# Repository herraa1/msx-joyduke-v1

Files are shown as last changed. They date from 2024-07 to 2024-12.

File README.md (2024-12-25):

# Microsoft Xbox Original controller adapter for MSX (msx-joyduke) v1

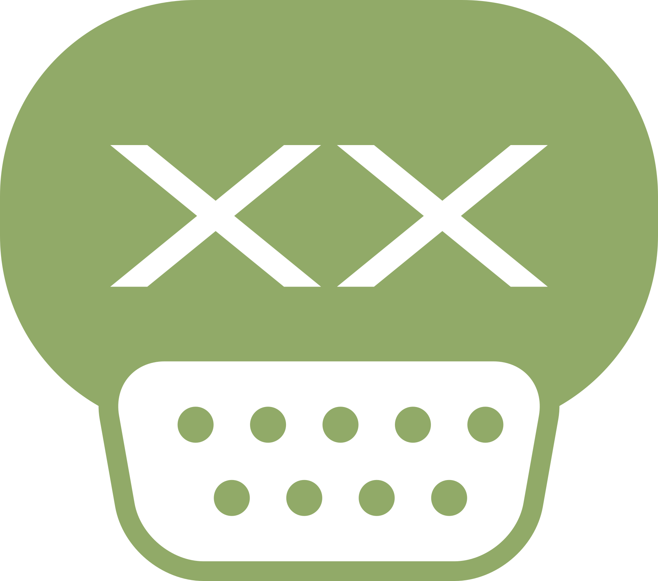
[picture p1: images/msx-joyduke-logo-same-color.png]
[](images/msx-joyduke-logo-same-color.png)

Connect [Microsoft Xbox Original controllers](https://en.wikipedia.org/wiki/Xbox_controller) to [MSX computers](https://www.msx.org/wiki/).

> [!NOTE]
>
> No build instructions are yet provided, but if you are brave enough go for the [recommended build](#recommended-build).
>

## Introduction

The msx-joyduke v1 is an adapter that allows connecting Microsoft Xbox Original controllers to [MSX general purpose I/O ports](https://www.msx.org/wiki/General_Purpose_port).

The main features of the msx-joyduke v1 adapter are:
* made of widely available electronic components
* behaves as a cord extension between the MSX computer and the Microsoft Xbox Original controller
* uses a female standard DE9 connector on the adapter's MSX joystick side
* uses a Xbox Controller socket on the adapter's Microsoft Xbox Original controller side
* formally requires an external USB power supply as the adapter draws slightly more current than a MSX general purpose I/O interface can officially provide
* optionally, can be powered using a MSX general purpose I/O interface without an external power supply if your MSX can safely supply enough current
* power consumption of ~20mA for the adapter itself, between ~55mA and ~85mA depending on the Xbox controller connected
* serial debug provides information about the operation of the adapter

## [Hardware](hardware/kicad/)

The msx-joyduke v1 adapter uses an [Atmega328p](https://en.wikipedia.org/wiki/ATmega328) and a [MAX3421](https://www.analog.com/media/en/technical-documentation/data-sheets/max3421e.pdf) to convert the [Microsoft Xbox Original controller USB signalling](https://xboxdevwiki.net/Xbox_Input_Devices#USB_Adapters) to the [MSX joystick standard signalling](https://www.msx.org/wiki/Joystick_control).

A two-sided printed circuit board (PCB) is used to put together all components:
* An Atmega328p as the main MCU working at +3.3V and clocked at 8MHz
* A MAX3421 USB Host Controller with SPI interface
* A TPS2051C 500mA current limited switch for the host controller USB port
* An AMS1117-3.3 regulator to convert the 5V from the joystick or the mini USB port to the 3.3V used by the Atmega328p and the MAX3421 chips
* Two 74LS03 quad 2-input NAND gates with open collectors to completely mimic the standard MSX joystick behavior
* A PTC fuse to minimize damage to the MSX computer in case something goes wrong with the board
* Several additional required components (crystals/resonators, diodes, leds, resistors, ceramic capacitors and alumionium capacitors)
* A 9pin PH2.0 connector is used to connect the MSX cable extension
* A 5pin PH2.0 connector is used to connect the Xbox cable extension
* A 2.54 pitch debug header is added for serial debug and programming
* An ICSP header is provided for burning a bootloader or to flash the chip using a hardware programmer

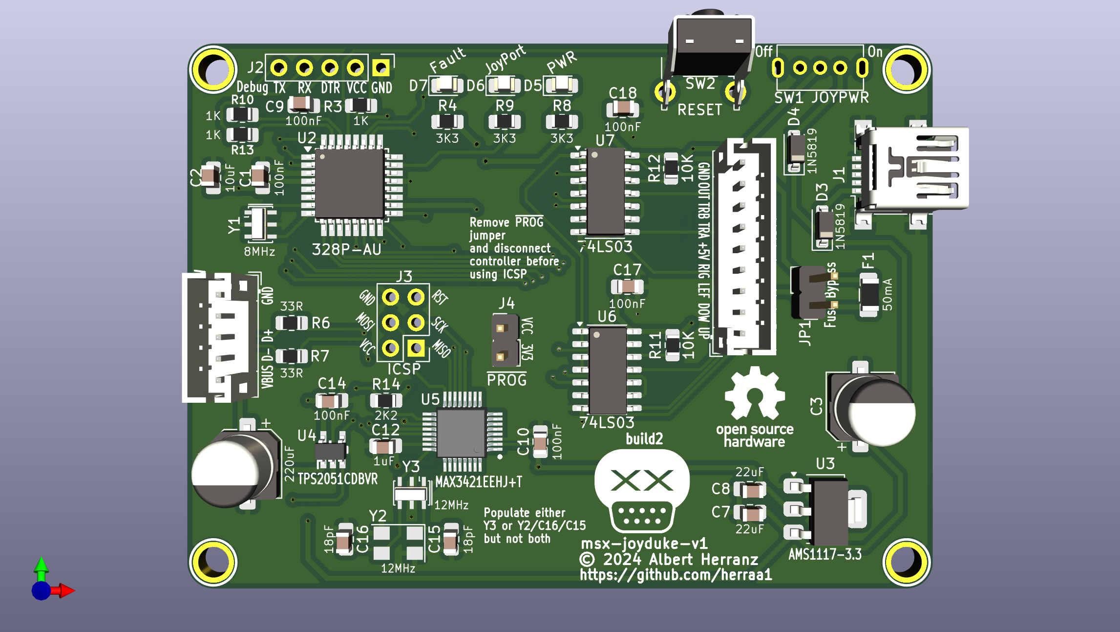
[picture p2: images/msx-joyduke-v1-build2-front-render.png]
[](images/msx-joyduke-v1-build2-front-render.png)
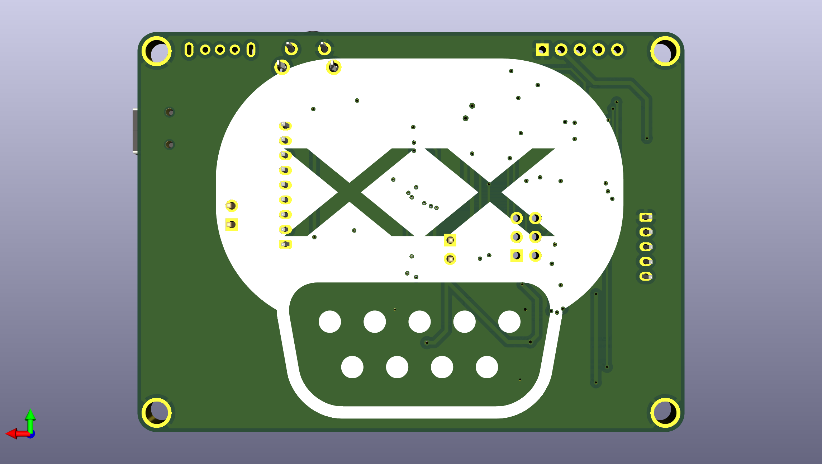
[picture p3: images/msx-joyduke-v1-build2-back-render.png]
[](images/msx-joyduke-v1-build2-back-render.png)

Connection to the MSX general purpose I/O port is implemented using a DE9 joystick extension cable with a female DE9 connector on one side and a loose end on the other side.
The MSX joystick extension cable loose end is wired according to the following pinout mapping.

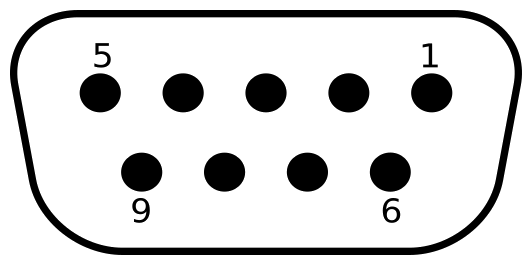
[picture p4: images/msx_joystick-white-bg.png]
| [](images/msx_joystick-white-bg.png) |
|:--|
| MSX joystick connector pinout, from controller plug side |

| MSX side pin | Cable color (may vary) | Signal |
| --- | --- | --- |
| 5 | Brown | +5v |
| 4 | Orange | RIGHT  |
| 3 | Grey | LEFT |
| 2 | Black | DOWN |
| 1 | Red | UP |
| 6 | Green | TRIGA  |
| 7 | White | TRIGB  |
| 8 | Blue | OUT |
| 9 | Yellow | GND |

The msx-joyduke-v1 is fully compatible with MSX joysticks and honors the pin8 (OUT) signal.

Connection to the Microsoft Xbox Original controller is done via a PC USB for Microsoft Xbox Original controller converter adapter cable with a male socket (the ones present on the Xbox console itself).

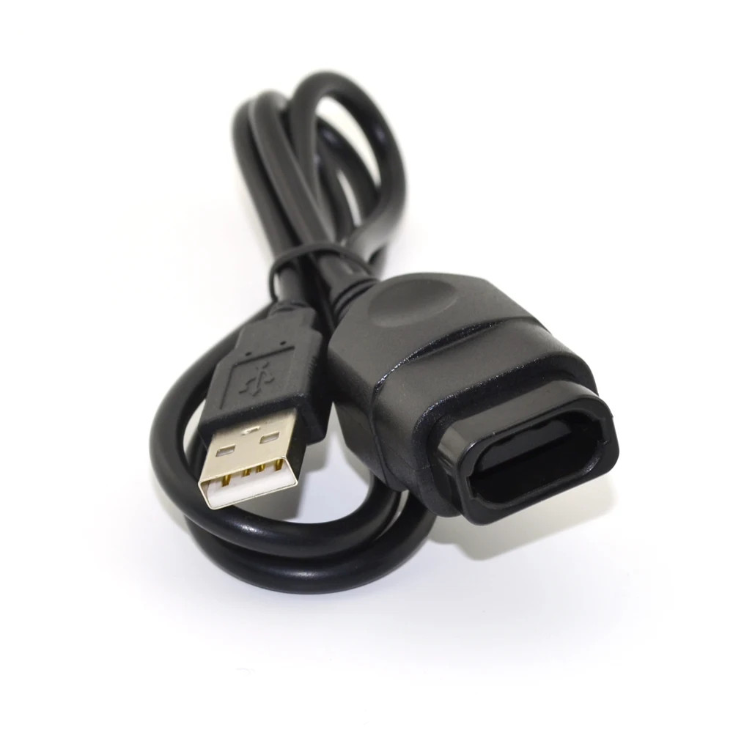
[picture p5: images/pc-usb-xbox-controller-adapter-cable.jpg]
| [](images/pc-usb-xbox-controller-adapter-cable.jpg) |
|:--|
| PC USB for Microsoft Xbox Original controller adapter cable |

The cable is severed to get rid of the USB side (which can be used for other projects) exposing the USB wiring.

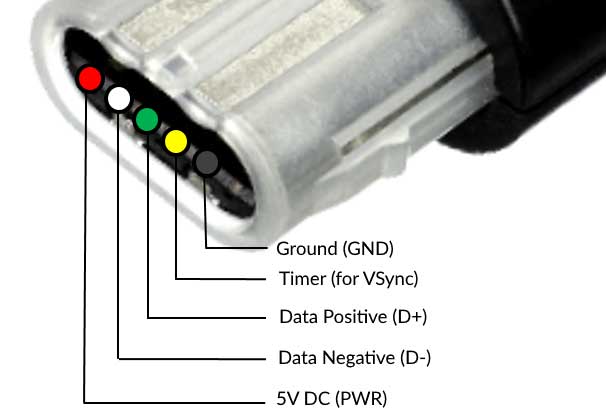
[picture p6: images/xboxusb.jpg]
| [](images/xboxusb.jpg) |
|:--|
| Microsoft Xbox Original connector pinout, from Microsoft Xbox Original controller side |

| Cable color official | Signal | Comment |
| ---| --- | --- |
| Green | D+ | USB Data + |
| White | D- | USB Data - |
| Yellow | VSync | (not used) |
| Black | GND | ground |
| Red | +5V | +5V power |

The Microsoft Xbox Original controller uses 5V for power and logic.

### Recommended Build

Please, use [msx-joyduke-v1 Build2](#build2) for making new boards.

### [Build2](hardware/kicad/msx-joyduke-v1-build2)

[Bill Of Materials (BoM)](https://html-preview.github.io/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)

This is the first publicly released build of the msx-joyduke adapter.

## [Firmware](firmware/msx-joyduke-v1/)

The msx-joyduke v1 adapter firmware uses the [USB Host Shield 2.0 library](https://github.com/felis/USB_Host_Shield_2.0) to read the Microsoft Xbox Original controller status.

While developing the firmware, I noticed that some Xbox Original controllers were not working as expected. After a bit of troubleshooting the root cause was found and a [modification](https://github.com/felis/USB_Host_Shield_2.0/commit/b92fa02546dddd2278cd411e5d0e2d2ff614c8d8) to the library has been submitted and merged to fix the problem.

The following elements are used as inputs:
* digital pad (D-Pad), as direction arrows
* left and right analog pad as direction arrows
* A button, as Trigger 1
* B button, as Trigger 2

Those elements' status are processed by the msx-joyduke firmware and transformed into MSX general purpose I/O port's signals on the fly.

## [Enclosure](enclosure/)

### Acrylic

A simple acrylic enclosure design for the project is provided to protect the electronic components and provide strain relief for the extension cords.

The enclosure uses a 3mm acrylic sheet.

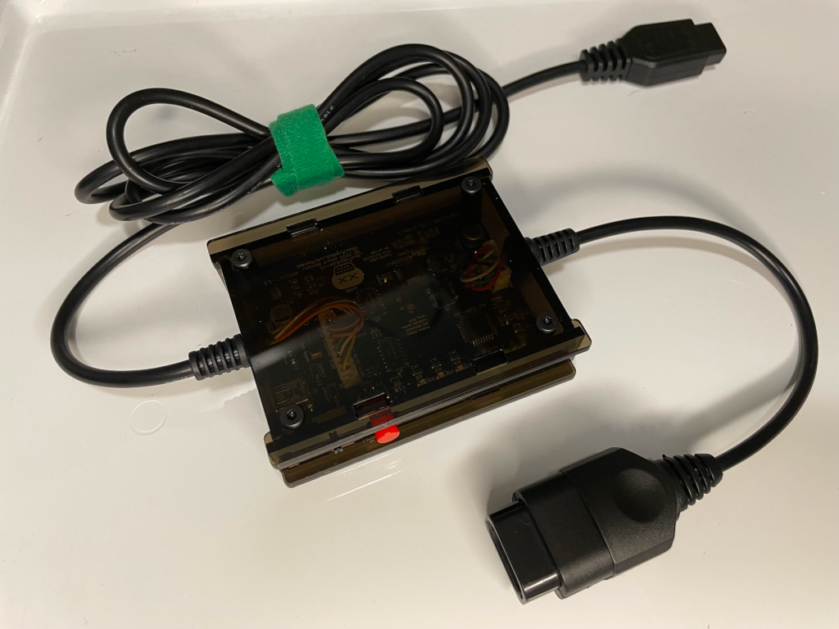
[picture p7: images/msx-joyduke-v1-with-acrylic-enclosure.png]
[](images/msx-joyduke-v1-with-acrylic-enclosure.png)

## Powering the msx-joyduke adapter

The msx-joyduke adapter uses under ~20mA when operating without a controller connected, but the power consumption can rise to ~85mA when an Xbox controller is connected.

On the other hand, a single MSX general purpose I/O interface is capable of delivering up to 50mA according to the MSX standard [^1].

That means that we are slightly over the max current specification for the MSX general purpose I/O interface.

Thus, the safest way to power the msx-joyduke adapter is by powering it via the USB mini connector of the board using an external 5V USB power supply. The board automatically powers up when using the USB mini connector without enabling any switch.

Nevertheless, even if the MSX especification puts such a low limit on the current that can be drawn from a general purpose I/O interface, real MSX hardware usually can safely deliver enough current for the msx-joyduke adapter to work correctly without harming our beloved classic computers.

Taking that into account, the msx-joyduke adapter has been enabled to be optionally powered by the a MSX general purpose I/O interface port.

To enable powering the msx-joyduke adapter from the _MSX Joystick Port_, the switch SW1 _JOYPWR_ must be first turned on by sliding the switch handle to the left.

> [!NOTE]
> A [1N5819 SMD Schottky diode](https://www.diodes.com/assets/Datasheets/1N5819HW.pdf) D4 is used to avoid leaking current from the msx-joyduke adapter to the MSX in case the msx-joyduke adapter is powered by USB while the _JOYPWR_ switch is ON.
> Another [1N5819 SMD Schottky diode](https://www.diodes.com/assets/Datasheets/1N5819HW.pdf) D3 prevents backpowering the USB side from the MSX side.
> And a Positive Temperature Coeficient (PTC) resettable fuse F1 of 50mA protects the MSX general purpose I/O interface port from excess of current in case something goes horribly wrong on the msx-joyduke adapter side.

To power the msx-joyduke adapter using a MSX general purpose I/O interface we must first understand how the PTC protections on the msx-joyduke adapter are implemented.

The selected PTC is rated for 50mA which is the so called Hold Current (the maximum current that can flow in normal operation). There is also the Trip Current (the minimum current necessary for the PTC to move to high-resistance state) which for the selected PTCs is around 100mA. Those thresholds are dependent on temperature and voltage. And to make things more undeterministic, the behavior of the PTC when current is between those thresholds is undefined (it may trip or not).

In normal operation and for a room temperature of around 25 degrees Celsius, the selected PTCs in practice never trip below 75mA.

> [!NOTE]
> Depending on the exact PTCs installed, the trip current may be slightly different and the adapter may trip at a different point. Unless you buy the PTCs from a reliable source, it is very difficult to know the exact PTC specifications. 
>
> Remember that the PTCs are provided as a safeguard in case something goes really wrong on the adapter, not to act as an exact current limiter to strictly comply with the 50mA per-port MSX specification.

A jumper JP1 can be used to bypass the PTC protections for the _MSX Joystick Port_.

> [!WARNING]
> Bypassing the PTC protection may damage your MSX computer.
> Do not bypass the PTC protections unless you known what you are doing.

By closing JP1 and **if our MSX computer can safely provide more than 85mA on a single MSX general purpose I/O interface**, we can connect the _MSX Joystick Port_ to the MSX computer and turn on the SW1 _JOYPWR_ switch to power the msx-joyduke adapter using a single joystick port.

In summary, we can use the following options to power the msx-joyduke adapter (from safest to less safe):
* via the board USB mini conector
  * turn off the SW1 _JOYPWR_ switch
  * connect a 5V USB power supply to the board USB mini connector
* via one of the MSX general purpose I/O interface, if your MSX can safely provide more than 85mA on each MSX general purpose I/O interface
  * close jumper JP1
  * turn on the SW1 _JOYPWR_ switch
  * connect the _MSX Joystick Port_ to a MSX general purpose I/O interface

## Switches and Buttons

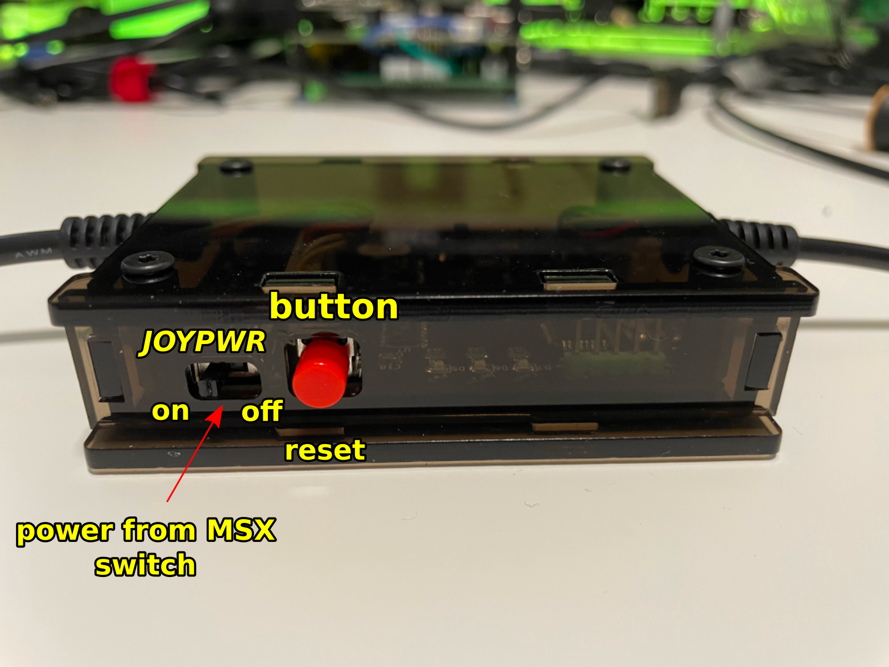
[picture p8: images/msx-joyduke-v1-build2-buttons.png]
[](images/msx-joyduke-v1-build2-buttons.png)

| **Switch** | **State** | **Description** |
|---|---|---|
| _JOYPWR_ | Off | power from MSX computer via a joystick port is off (except logic gates)  |
| _JOYPWR_ | On | board electronics get power from MSX computer via a joystick port |

> [!NOTE]
> If you plug a +5V USB power supply to the USB mini connector, the adapter will turn on unconditionally irrespective of the _JOYPWR_ switch position.
>

| **Button** | **Description** |
|---|---|
| RESET | restart the firmware |

## LED indicators

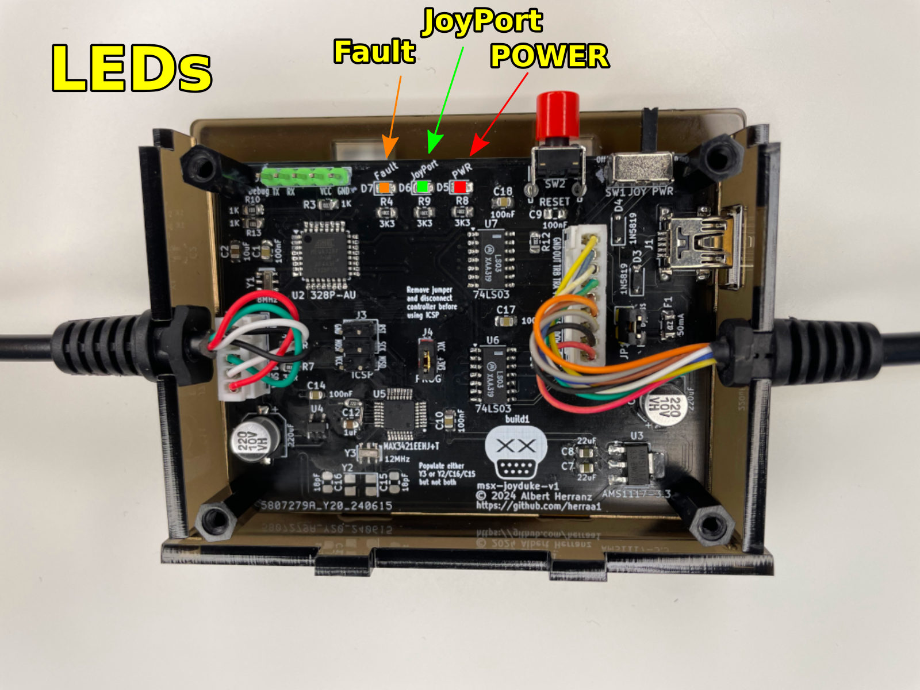
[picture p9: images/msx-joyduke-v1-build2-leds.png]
[](images/msx-joyduke-v1-build2-leds.png)

| **LED** | **State** | **Indication** |
|---|---|---|
| _POWER_ | Off | board is not receiving 3V3 power |
| _POWER_ | Solid Red | board is receiving 3V3 power |
| _JoyPort_ | Off | no Xbox controller connected or recognized |
| _JoyPort_ | Solid Green | Xbox controller connected and ready to use |
| _Fault_ | Off | no power fault detected |
| _Fault_ | Solid Yellow | excess of current detected on the Xbox connector |

## Compatibility Tests

| **Controller** | **Compatible** |
|---|---|
| 045e:0202 Microsoft X-Box pad v1 (US) | YES |
| 045e:0289 Microsoft X-Box pad v2 (US) | YES |

Other Xbox controllers may work but have not been tested.

## References

MSX general purpose I/O port
* https://www.msx.org/wiki/General_Purpose_port

Xbox controller pinout and protocol
* https://chris-donnelly.github.io/xboxpad.html

Atmega328p pinout
- https://camo.githubusercontent.com/18796d8b7673e3b6c14b6bdfb61d86b58c6f0d670398973abd4207afce960277/68747470733a2f2f692e696d6775722e636f6d2f6e6177657145362e6a7067

USB Host Shield 2.0 Library
* https://github.com/felis/USB_Host_Shield_2.0

[^1]: https://www.msx.org/wiki/General_Purpose_port

## Image Sources

* https://www.oshwa.org/open-source-hardware-logo/
* https://en.wikipedia.org/wiki/File:Numbered_DE9_Diagram.svg

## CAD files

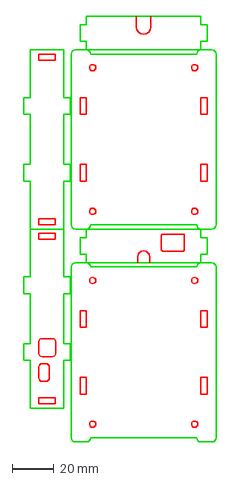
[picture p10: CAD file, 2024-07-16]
enclosure/msx-joyduke-v1-case-acrylic-3mm-ready-to-lasercut.dxf
92.3 x 204.5 mm

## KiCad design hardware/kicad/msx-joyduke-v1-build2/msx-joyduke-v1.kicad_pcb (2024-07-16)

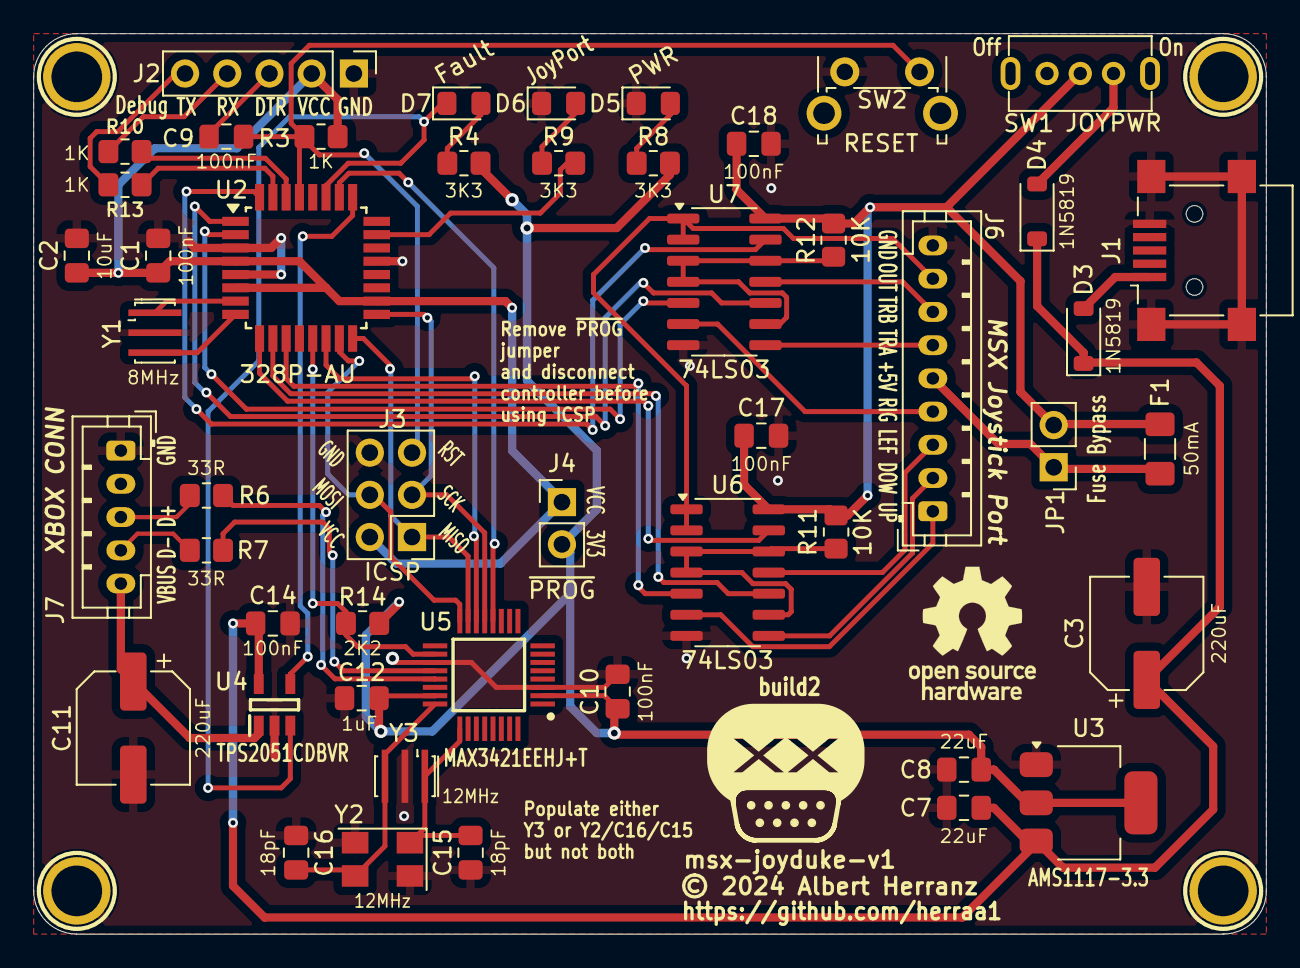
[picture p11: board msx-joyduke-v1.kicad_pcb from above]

Board: 2 copper layers, 74.2 x 54.2 mm, 54 parts (0 on the bottom side), 50 nets.

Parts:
C1, C9, C10, C14, C17, C18: 100nF; C_0805_2012Metric_Pad1.18x1.45mm_HandSolder
C2: 10uF; C_0805_2012Metric_Pad1.18x1.45mm_HandSolder
C3, C11: 220uF; CP_Elec_6.3x5.4
C7, C8: 22uF; C_0805_2012Metric_Pad1.18x1.45mm_HandSolder
C12: 1uF; C_0805_2012Metric_Pad1.18x1.45mm_HandSolder
C15, C16: 18pF; C_0805_2012Metric_Pad1.18x1.45mm_HandSolder
D3, D4: 1N5819; D_SOD-123
D5: PWR; LED_0805_2012Metric_Pad1.15x1.40mm_HandSolder
D6: JoyPort; LED_0805_2012Metric_Pad1.15x1.40mm_HandSolder
D7: Fault; LED_0805_2012Metric_Pad1.15x1.40mm_HandSolder
F1: 50mA; Fuse_1206_3216Metric_Pad1.42x1.75mm_HandSolder
HOLE1, HOLE2, HOLE3, HOLE4: HOLE; Hole_3mm
J1: USB_B_Mini; USB_Mini-B_Lumberg_2486_01_Horizontal
J2: Debug; PinHeader_1x05_P2.54mm_Vertical
J3: ICSP; PinHeader_2x03_P2.54mm_Vertical
J4: ~{PROG}; PinHeader_1x02_P2.54mm_Vertical
J6: MSX Joystick Port; JST_PH_B9B-PH-K_1x09_P2.00mm_Vertical
J7: XBOX CONN; JST_PH_B5B-PH-K_1x05_P2.00mm_Vertical
JP1: Fuse Bypass; PinHeader_1x02_P2.54mm_Vertical
R3, R10, R13: 1K; R_0805_2012Metric_Pad1.20x1.40mm_HandSolder
R4, R8, R9: 3K3; R_0805_2012Metric_Pad1.20x1.40mm_HandSolder
R6, R7: 33R; R_0805_2012Metric_Pad1.20x1.40mm_HandSolder
R11, R12: 10K; R_0805_2012Metric_Pad1.20x1.40mm_HandSolder
R14: 2K2; R_0805_2012Metric_Pad1.20x1.40mm_HandSolder
SW1: JOYPWR; SW_SK-12D07G6-1P2T-6mm
SW2: RESET; SW_Tactile_SPST_Angled_PTS645Vx39-2LFS
SYM1: Logo_Open_Hardware_Large; OSHW-Logo_7.5x8mm_SilkScreen
U2: 328P-AU; TQFP-32_7x7mm_P0.8mm
U3: AMS1117-3.3; SOT-223-3_TabPin2
U4: TPS2051CDBVR; SOT95P280X145-5N
U5: MAX3421EEHJ+T; QFP50P700X700X120-32N
U6, U7: 74LS03; SOIC-14_3.9x8.7mm_P1.27mm
Y1: 8MHz; Resonator_SMD_Murata_CSTxExxV-3Pin_3.0x1.1mm_HandSoldering
Y2: 12MHz; Crystal_SMD_5032-4Pin_5.0x3.2mm
Y3: 12MHz; Resonator_SMD_Murata_CSTxExxV-3Pin_3.0x1.1mm_HandSoldering

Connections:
+3V3_REG: C8.1, C10.1, C12.1, J4.2, R4.2, R8.2, R14.1, U3.2 (VO), U5.2 (VL), U5.23 (VCC)
+5V_FILT: C3.1, C7.1, C14.1, D3.1 (K), D4.1 (K), U3.3 (VI), U4.5 (IN)
/+3V3_LED: D5.2 (A), R8.1
/D0/RX: R10.1, U2.30 (PD0)
/D1/TX: R13.1, U2.31 (PD1)
/DTR: C9.2, J2.3
/D_N: J7.4, R7.2
/D_P: J7.3, R6.2
/GPIO_J1_DOWN: U2.10 (PD6), U6.10
/GPIO_J1_LEFT: U2.9 (PD5), U6.13
/GPIO_J1_RIGHT: U2.2 (PD4), U7.5
/GPIO_J1_TRIGA: U2.1 (PD3), U7.10
/GPIO_J1_TRIGB: U2.32 (PD2), U7.13
/GPIO_J1_UP: U2.11 (PD7), U6.5
/J1_DOWN: J6.2, U6.8
/J1_LEFT: J6.3, U6.11
/J1_OUT: J6.8, U6.1, U6.2, U7.1, U7.2
/J1_RIGHT: J6.4, U7.6
/J1_TRIGA: J6.6, U7.8
/J1_TRIGB: J6.7, U7.11
/J1_UP: J6.1, U6.6
/JOY_EXT_5V: D4.2 (A), SW1.1 (A)
/MISO: J3.1, U2.16 (PB4), U5.15 (MISO)
/MOSI: J3.4, U2.15 (PB3), U5.16 (MOSI)
/RESET: C9.1, J3.5, R3.2, SW2.2, U2.29 (~RESET/PC6)
/SCK: J3.3, U2.17 (PB5), U5.13 (SCLK)
/SS: U2.14 (PB2), U5.14 (~SS)
/USB_EXT_5V: D3.2 (A), J1.1 (VBUS)
/~J1_OUT_1: R11.2, U6.3, U6.4, U6.9, U6.12
/~J1_OUT_2: R12.2, U7.3, U7.4, U7.9, U7.12
FAULT: D7.1 (K), U2.27 (PC4), U4.3 (~FLT)
GND: C1.2, C2.2, C3.2, C7.2, C8.2, C10.2, C11.2, C12.2, C14.2, C15.1, C16.1, C17.2, C18.2, D5.1 (K), D6.1 (K), HOLE1.1, HOLE2.1, HOLE3.1, HOLE4.1, J1.5 (GND), J1.6 (Shield), J2.1, J3.6, J6.9, J7.1, SW2.1, U2.3 (GND), U2.5 (GND), U2.21 (GND), U3.1 (GND), U4.2 (GND), U5.3 (GND_1), U5.19 (GND_2), U6.7 (GND), U7.7 (GND), Y1.2, Y2.2, Y2.4, Y3.2
INT1: R14.2, U2.13 (PB1), U5.18 (INT)
J1_PWR: F1.1, J6.5, JP1.1 (A)
JOY_5V: C17.1, C18.1, F1.2, JP1.2 (B), R11.1, R12.1, SW1.2 (B), U6.14 (VCC), U7.14 (VCC)
LED_J1: R9.2, U2.23 (PC0)
MCU_VCC: C1.1, C2.1, J2.2, J3.2, J4.1, R3.1, U2.4 (VCC), U2.6 (VCC), U2.18 (AVCC)
unnamed: D6.2 (A), R9.1
unnamed: D7.2 (A), R4.1
unnamed: U2.7 (XTAL1/PB6), Y1.1
unnamed: U2.8 (XTAL2/PB7), Y1.3
unnamed: R6.1, U5.21 (D+)
unnamed: R7.1, U5.20 (D-)
UART_RX: J2.4, R10.2
UART_TX: J2.5, R13.2
UHC_EN: U2.26 (PC3), U5.12 (~RES)
VBUS: C11.1, J7.5, U4.1 (OUT)
VUSB_EN: U2.25 (PC2), U4.4 (EN/~EN)
XTAL_0: C15.2, U5.25 (XO), Y2.1, Y3.1
XTAL_1: C16.2, U5.24 (XI), Y2.3, Y3.3

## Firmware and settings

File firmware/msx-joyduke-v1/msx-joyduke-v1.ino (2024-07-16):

/*
 * msx-joyduke v1, an original Xbox controller to MSX joystick adapter
 * Copyright (C) 2024 Albert Herranz
 *
 * This code is released under GPL V2.0
 *
 * Valid-License-Identifier: GPL-2.0-only
 * SPDX-URL: https://spdx.org/licenses/GPL-2.0-only.html
 *
 * Based on USB Host Shield 2.0 library
 * - https://github.com/felis/USB_Host_Shield_2.0
 *
 * Other references:
 * - https://chris-donnelly.github.io/xboxpad.html
 * - https://github.com/felis/USB_Host_Shield_2.0
 * - https://www.pjrc.com/teensy/td_libs_USBHostShield.html
 * - https://chrz.de/2023/12/05/fido2-hardware-part-2-usb-host-circuit-boards/
 * - https://www.msx.org/wiki/General_Purpose_port
 * - https://github.com/MCUdude/MiniCore
 * - https://www.arduino.cc/en/software
 */

/*
 Example sketch for the original Xbox library - developed by Kristian Lauszus
 For more information visit my blog: http://blog.tkjelectronics.dk/ or
 send me an e-mail:  kristianl@tkjelectronics.com
 */

/*
 SS           YELLOW atmega328p -> usbhs                 3.3V  ss (slave select)  10 yellow
 MOSI         ORANGE atmega328p -> usbhs                 3.3V  mosi               11 orange
 MISO         BROWN  usbhs -> atmega328p  open-collector 3.3V  miso               12 brown
 CLK          BLUE   atmega328p -> usbhs                 3.3V  sck                13 blue

 INT          WHITE                                                                9 white

 UHC_EN                                                                           A3
 VUSB_EN                                                                          A2
 green led                                                                        A0

*/
#define DEBUG
#include <XBOXOLD.h>
#include <usbhub.h>

// Satisfy the IDE, which needs to see the include statment in the ino too.
#ifdef dobogusinclude
#include <spi4teensy3.h>
#endif
#include <SPI.h>

USB Usb;
USBHub Hub1(&Usb);  // The controller has a built in hub, so this instance is needed
XBOXOLD Xbox(&Usb);

const byte PIN_HAVECONTROLLER = A0;
const byte PIN_UHC_EN = A3;
const byte PIN_VUSB_EN = A2;

/*
 * Atmega328p pins for MSX signals.
 * Use PORTD for all MSX joystick arrow and buttons signals.
 * This allows to set them all at the same time.
 */
#define PORT_MSX_JOYSTICK PORTD
#define DDR_MSX_JOYSTICK DDRD

/* MSX general purpose signals as mapped to Atmega328p PORTD bits */
const int PORT_MSX_JOYSTICK_UP = 7;       /* PD7, MSX joystick pin1 */
const int PORT_MSX_JOYSTICK_DOWN = 6;     /* PD6, MSX joystick pin2 */
const int PORT_MSX_JOYSTICK_LEFT = 5;     /* PD5, MSX joystick pin3 */
const int PORT_MSX_JOYSTICK_RIGHT = 4;    /* PD4, MSX joystick pin4 */
const int PORT_MSX_JOYSTICK_TRIGGER1 = 3; /* PD3, MSX joystick pin6 */
const int PORT_MSX_JOYSTICK_TRIGGER2 = 2; /* PD2, MSX joystick pin7 */

volatile uint8_t curr_msx_joystick_signals = 0x00;

/* Microsoft original Xbox controller pad axis valid range */
#define XBOXOLD_AXIS_MIN -32768
#define XBOXOLD_AXIS_MAX  32767

/*
 * Discrete thresholds for Microsoft Xbox joystick analog pad axis:
 * - Values below the min threshold on the horizontal/vertical axis indicate
 *   left/down active, respectively.
 * - Values above the max threshold on the horizontal/vertical axis indicate
 *   right/up active, respectively.
 */
int16_t axis_threshold_min, axis_threshold_max;

/* serial output width control */
uint8_t output_width_count = 0;

#ifdef DEBUG
void print_hex8(uint8_t data)
{
  char tmp[2 + 1];
  byte nibble;

  nibble = (data >> 4) | 48;
  tmp[0] = (nibble > 57) ? nibble + (byte)39 : nibble;
  nibble = (data & 0x0f) | 48;
  tmp[1] = (nibble > 57) ? nibble + (byte)39 : nibble;
  tmp[2] = 0;

  Serial.print(tmp);
}

void print_hex16(uint16_t data)
{
  print_hex8((uint8_t)(data >> 8));
  print_hex8((uint8_t)(data & 0xff));
}
#endif

void print_rolling_sequence(void)
{
  static char rolling_chars[] = { '-', '\\', '|', '/' };
  static uint8_t rolling_index = 0;

  //Serial.write(8);
  Serial.print(rolling_chars[rolling_index++]);
  if (rolling_index >= sizeof(rolling_chars))
    rolling_index = 0;
}

inline void __update_msx_signals(uint8_t signals)
{
  /* write all signal states at once to MSX side */
  PORT_MSX_JOYSTICK = (signals);
  DDR_MSX_JOYSTICK = (~0);
}

void setup()
{
  int16_t axis_threshold;

  pinMode(PIN_HAVECONTROLLER, OUTPUT);
  pinMode(PIN_UHC_EN, OUTPUT);
  pinMode(PIN_VUSB_EN, OUTPUT);

  __update_msx_signals(curr_msx_joystick_signals);

  Serial.begin(115200);
  Serial.println(F("msx-joyduke-v1 20240630_1"));

  /*
     * Calculate XBOX controller analog pad thresholds.
     * Analog pad needs to be pushed from its origin in one direction at least
     * 1/6 of the complete run to get active
     */
  axis_threshold = (XBOXOLD_AXIS_MAX - XBOXOLD_AXIS_MIN) / 3;
  axis_threshold_min = XBOXOLD_AXIS_MIN + axis_threshold;
  axis_threshold_max = XBOXOLD_AXIS_MAX - axis_threshold;

  Serial.print("axis_threshold_max: ");
  Serial.println(axis_threshold_max);
  Serial.print("axis_threshold_min: ");
  Serial.println(axis_threshold_min);

  digitalWrite(PIN_VUSB_EN, HIGH);
  delay(150);
  digitalWrite(PIN_UHC_EN, HIGH);

  if (Usb.Init() == -1) {
    Serial.println(F("OSC did not start, halting!"));
    while (1)
      ;  // halt
  }
  Serial.println(F("XBOX Library Started"));
}

void (*soft_reset)(void) = 0;

void loop()
{
  static unsigned long last_health_check;
  static int16_t slx, sly, srx, sry;
  int16_t lx, ly, rx, ry;

  Usb.Task();

  if (millis() - last_health_check > 1000) {
    last_health_check = millis();

    uint8_t HIRQ;
    HIRQ = Usb.regRd(rHIRQ);  //determine interrupt source
    if (HIRQ == 0xff) {
      // something went wrong with the MAX3421, restart the whole thing
      Serial.println(F("MCU RESTART!"));
      delay(5);
      soft_reset();
    }
  }

  if (Xbox.XboxConnected) {
    digitalWrite(PIN_HAVECONTROLLER, HIGH);

    uint8_t msx_joystick_signals = 0x00;

    lx = Xbox.getAnalogHat(LeftHatX);
    ly = Xbox.getAnalogHat(LeftHatY);
    rx = Xbox.getAnalogHat(RightHatX);
    ry = Xbox.getAnalogHat(RightHatY);

#ifdef DEBUG    
    bool need_lf;

    if (Xbox.getButtonPress(BLACK) || Xbox.getButtonPress(WHITE)) {
      Serial.print("BLACK: ");
      Serial.print(Xbox.getButtonPress(BLACK));
      Serial.print("\tWHITE: ");
      Serial.println(Xbox.getButtonPress(WHITE));
      //Xbox.setRumbleOn(Xbox.getButtonPress(BLACK), Xbox.getButtonPress(WHITE));
    } else
      /*Xbox.setRumbleOn(0, 0)*/;

    if (Xbox.getButtonClick(START))
      Serial.println(F("Start"));
    if (Xbox.getButtonClick(BACK))
      Serial.println(F("Back"));
    if (Xbox.getButtonClick(L3))
      Serial.println(F("L3"));
    if (Xbox.getButtonClick(R3))
      Serial.println(F("R3"));

    if (Xbox.getButtonPress(A)) {
      Serial.print(F("A: "));
      Serial.println(Xbox.getButtonPress(A));
    }
    if (Xbox.getButtonPress(B)) {
      Serial.print(F("B: "));
      Serial.println(Xbox.getButtonPress(B));
    }
    if (Xbox.getButtonPress(X)) {
      Serial.print(F("X: "));
      Serial.println(Xbox.getButtonPress(X));
    }
    if (Xbox.getButtonPress(Y)) {
      Serial.print(F("Y: "));
      Serial.println(Xbox.getButtonPress(Y));
    }
    if (Xbox.getButtonPress(LT)) {
      Serial.print(F("LT: "));
      Serial.println(Xbox.getButtonPress(LT));
    }
    if (Xbox.getButtonPress(RT)) {
      Serial.print(F("RT: "));
      Serial.println(Xbox.getButtonPress(RT));
    }

    need_lf = false;
    if (lx > 7500 || lx < -7500) {
        if (lx != slx) {
            Serial.print(F("LeftHatX: "));
            Serial.print(lx);
            Serial.print("\t");
            need_lf = true;
        }
    }
    if (ly > 7500 || ly < -7500) {
        if (ly != sly) {
            Serial.print(F("LeftHatY: "));
            Serial.print(ly);
            Serial.print("\t");
            need_lf = true;
        }
    }
    if (need_lf)
        Serial.println();

    slx = lx;
    sly = ly;

    need_lf = false;
    if (rx > 7500 || rx < -7500) {
        if (rx != srx) {
            Serial.print(F("RightHatX: "));
            Serial.print(rx);
            Serial.print("\t");
            need_lf = true;
        }
    }
    if (ry > 7500 || ry < -7500) {
        if (ry != sry) {
            Serial.print(F("RightHatY: "));
            Serial.print(ry);
            Serial.print("\t");
            need_lf = true;
        }
    }
    if (need_lf)
        Serial.println();

    srx = rx;
    sry = ry;
#endif

    if (Xbox.getButtonPress(UP))
      msx_joystick_signals |= (1 << PORT_MSX_JOYSTICK_UP);
    if (Xbox.getButtonPress(DOWN))
      msx_joystick_signals |= (1 << PORT_MSX_JOYSTICK_DOWN);
    if (Xbox.getButtonPress(LEFT))
      msx_joystick_signals |= (1 << PORT_MSX_JOYSTICK_LEFT);
    if (Xbox.getButtonPress(RIGHT))
      msx_joystick_signals |= (1 << PORT_MSX_JOYSTICK_RIGHT);
    if (Xbox.getButtonPress(A))
      msx_joystick_signals |= (1 << PORT_MSX_JOYSTICK_TRIGGER1);
    if (Xbox.getButtonPress(B))
      msx_joystick_signals |= (1 << PORT_MSX_JOYSTICK_TRIGGER2);

    /* left analog hat */

    /* before activating DOWN check that UP is not activated */
    if ((ly < axis_threshold_min) && !(msx_joystick_signals & (1 << PORT_MSX_JOYSTICK_UP)))
      msx_joystick_signals |= (1 << PORT_MSX_JOYSTICK_DOWN);

    /* before activating UP check that DOWN is not activated */
    if ((ly > axis_threshold_max) && !(msx_joystick_signals & (1 << PORT_MSX_JOYSTICK_DOWN)))
      msx_joystick_signals |= (1 << PORT_MSX_JOYSTICK_UP);

    /* before activating LEFT check that RIGHT is not activated */
    if ((lx < axis_threshold_min) && !(msx_joystick_signals & (1 << PORT_MSX_JOYSTICK_RIGHT)))
      msx_joystick_signals |= (1 << PORT_MSX_JOYSTICK_LEFT);

    /* before activating RIGHT check that LEFT is not activated */
    if ((lx > axis_threshold_max) && !(msx_joystick_signals & (1 << PORT_MSX_JOYSTICK_LEFT)))
      msx_joystick_signals |= (1 << PORT_MSX_JOYSTICK_RIGHT);

    /* right analog hat */

    if ((ry < axis_threshold_min) && !(msx_joystick_signals & (1 << PORT_MSX_JOYSTICK_UP)))
      msx_joystick_signals |= (1 << PORT_MSX_JOYSTICK_DOWN);
    if ((ry > axis_threshold_max) && !(msx_joystick_signals & (1 << PORT_MSX_JOYSTICK_DOWN)))
      msx_joystick_signals |= (1 << PORT_MSX_JOYSTICK_UP);
    if ((rx < axis_threshold_min) && !(msx_joystick_signals & (1 << PORT_MSX_JOYSTICK_RIGHT)))
      msx_joystick_signals |= (1 << PORT_MSX_JOYSTICK_LEFT);
    if ((rx > axis_threshold_max) && !(msx_joystick_signals & (1 << PORT_MSX_JOYSTICK_LEFT)))
      msx_joystick_signals |= (1 << PORT_MSX_JOYSTICK_RIGHT);

    curr_msx_joystick_signals = msx_joystick_signals;
    __update_msx_signals(curr_msx_joystick_signals);
  } else {
    digitalWrite(PIN_HAVECONTROLLER, LOW);

    curr_msx_joystick_signals = 0x00;
    __update_msx_signals(curr_msx_joystick_signals);

    /* write rolling sequence while not connected */
    print_rolling_sequence();
    /* wrap output at 80 columns ... */
    if (output_width_count++ > 79) {
      output_width_count = 0;
      Serial.println("");
    }
  }
  delay(1);
}

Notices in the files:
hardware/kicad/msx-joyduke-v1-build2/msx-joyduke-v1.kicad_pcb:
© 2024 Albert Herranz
